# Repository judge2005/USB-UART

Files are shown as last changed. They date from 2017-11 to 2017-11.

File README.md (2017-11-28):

# USB-UART
A USB to serial adapter specifically designed for programming the ESP01. It uses node-mcu style programming, so no fiddling with buttons is necessary - just change the reset method to 'node-mcu'.

It has enough power to run the ESP01 without the need for an additional power source.

It uses the Silicon Labs CP2102N, so it can detect the charge protocol supported by the USB port it is plugged in to. You will have to use the Silicon Labs Express Configurator to set that up.

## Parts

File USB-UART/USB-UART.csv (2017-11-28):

Id | Designator | Package | Quantity | Designation | Supplier and ref
1 | C1,C2 | SparkFun-Capacitors-0603 | 2 | 1uF |  | got
2 | C3 | SparkFun-Capacitors-0603 | 1 | 4.7uF |  | got
3 | C4 | SparkFun-Capacitors-0603 | 1 | 0.1uF |  | got 50v x7r
5 | D1 | D_SOD-323_HandSoldering | 1 | D_Schottky_Small |  | Got
9 | J1 | SparkFun-Connectors-1X06_NO_SILK | 1 | UART |  | Got
10 | J2 | SparkFun-Connectors-1X04_NO_SILK | 1 | Power |  | got
12 | J5 | SparkFun-Connectors-1X03_NO_SILK | 1 | JumperV |  | got
13 | R1 | SparkFun-Resistors-0603 | 1 | 100k |  | got
15 | R3 | SparkFun-Resistors-0603 | 1 | 1K |  | got
16 | R4,R6,R7 | SparkFun-Resistors-0603 | 3 | 470 |  | got
17 | R5,R11 | SparkFun-Resistors-0603 | 2 | 10K |  | got
18 | U1 | nixiemisc-QFN28G_0.5-5X5MM | 1 | CP2102N |  | got
21 | J6 | SparkFun-Connectors-1X03_NO_SILK | 1 | JumperS |  | got
22 | R8,R9 | SparkFun-Resistors-0603 | 2 | 12K |  | got
23 | R10 | SparkFun-Resistors-0603 | 1 | 4.7K |  | got
24 | U4 | nixiemisc-UMT6 | 1 | UMH3NUMT6 |  | got
25 | J4 | SparkFun-Connectors-1X05_NO_SILK | 1 | Charge |  | got
27 | G*** | mermaid_l | 1 | LOGO |  | got
4 | C5 | SparkFun-Capacitors-0603 | 1 | 100pF |  | *
6 | D2 | SparkFun-LED-LED-0603 | 1 | SPND |  | yellow
7 | D3 | SparkFun-LED-LED-0603 | 1 | TX |  | red
8 | D4 | SparkFun-LED-LED-0603 | 1 | RX |  | green
11 | J3 | SparkFun-Connectors-USB-B-MICRO-SMD | 1 | USB_MICRO-B_FEMALE-SMT |  | *
14 | R2 | SparkFun-Resistors-0603 | 1 | 1M |  | *
19 | U2 | nixiemisc-SOT25 | 1 | AP2112 |  | *
20 | U3 | nixiemisc-SOT143 | 1 | ESD |  | got one, maybe get more *
26 | J7 | Socket_Strip_Straight_2x04_Pitch2.54mm | 1 | ESP01

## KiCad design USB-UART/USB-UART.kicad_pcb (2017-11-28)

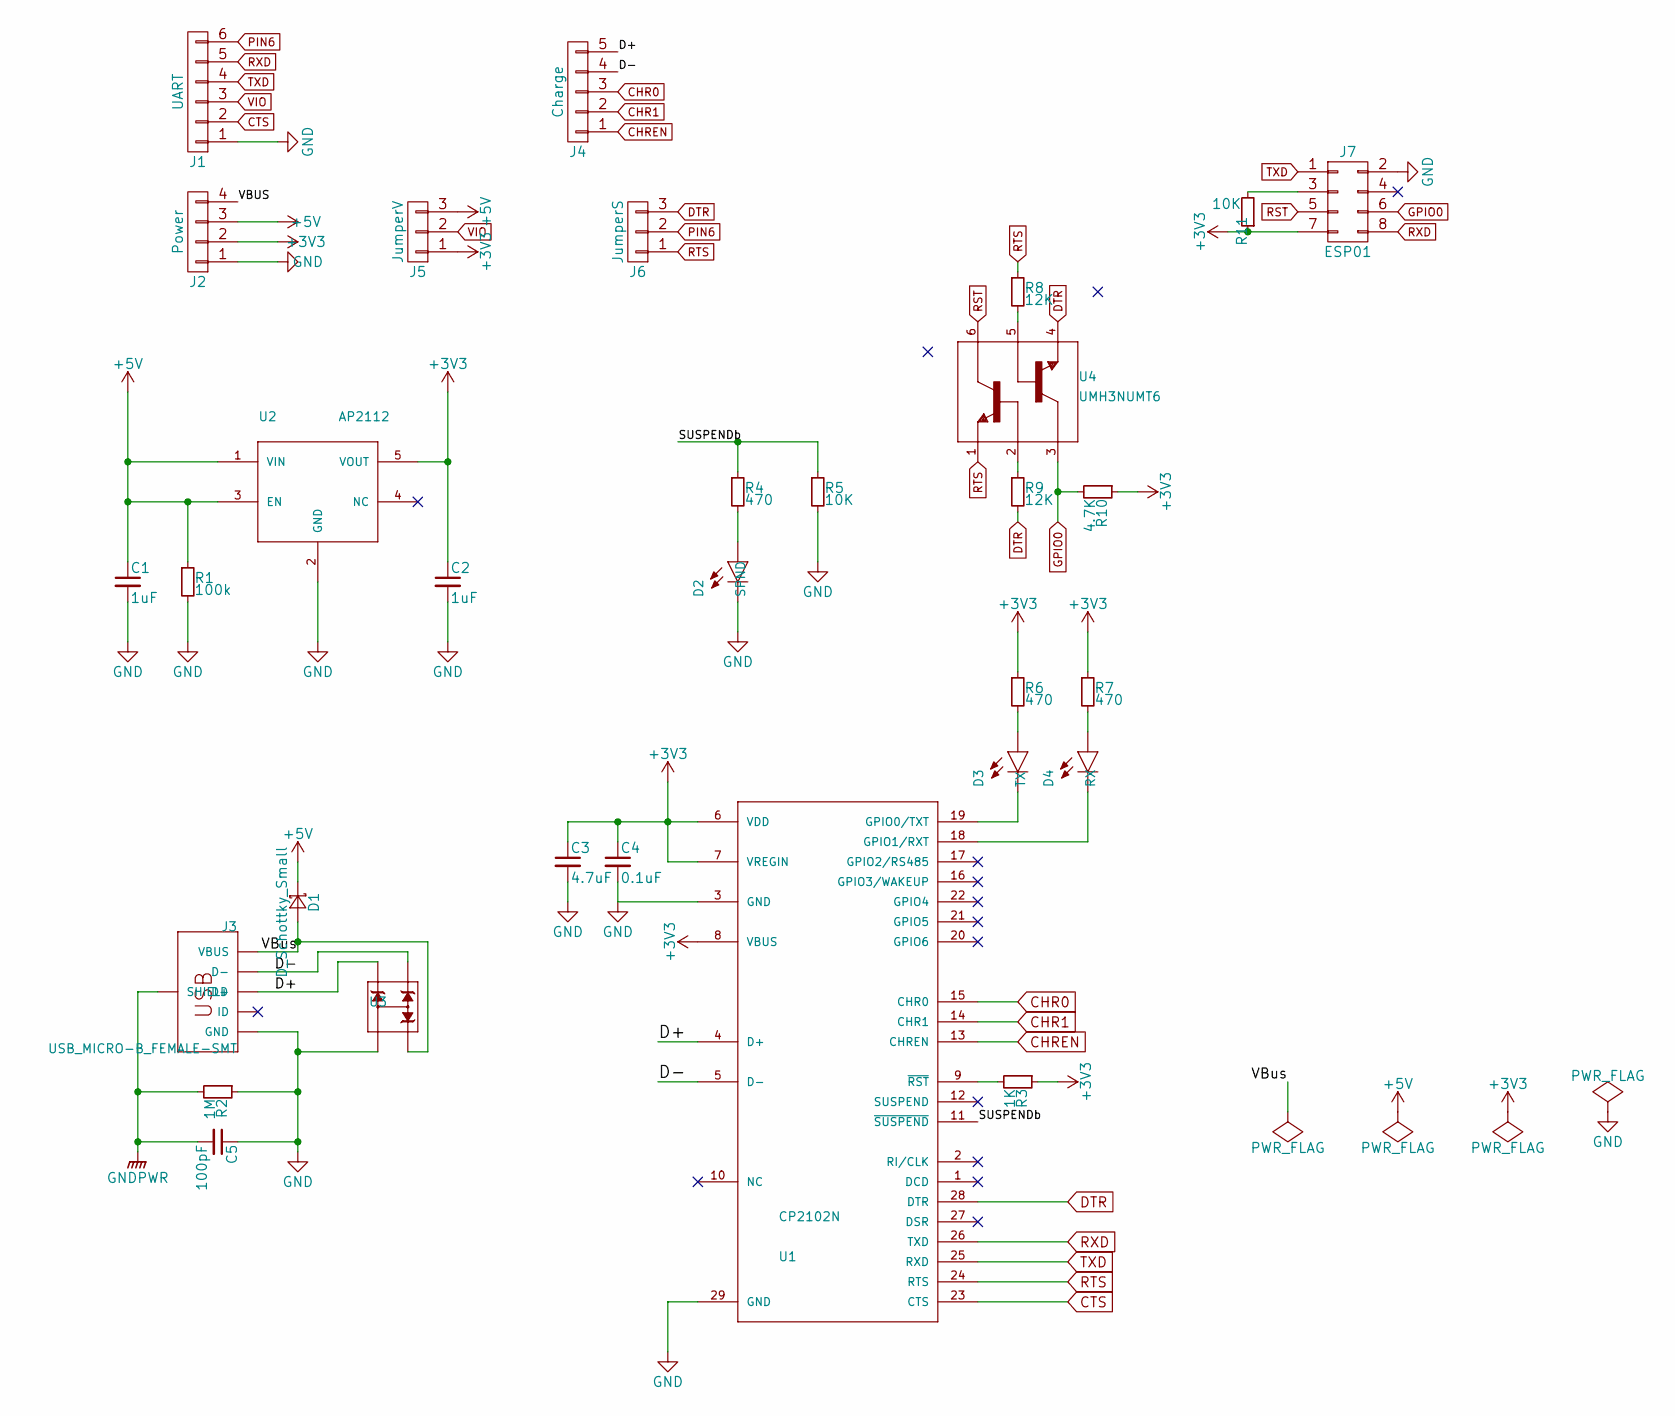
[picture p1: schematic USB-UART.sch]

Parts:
C1, C2: 1uF; SparkFun-Capacitors-0603
C3: 4.7uF; SparkFun-Capacitors-0603
C4: 0.1uF; SparkFun-Capacitors-0603
C5: 100pF; SparkFun-Capacitors-0603; Rating 1KV
D1: D_Schottky_Small; D_SOD-323_HandSoldering
D2: SPND; SparkFun-LED-LED-0603
D3: TX; SparkFun-LED-LED-0603
D4: RX; SparkFun-LED-LED-0603
J1: UART; SparkFun-Connectors-1X06_NO_SILK
J2: Power; SparkFun-Connectors-1X04_NO_SILK
J3: USB_MICRO-B_FEMALE-SMT; SparkFun-Connectors-USB-B-MICRO-SMD
J4: Charge; SparkFun-Connectors-1X05_NO_SILK
J5: JumperV; SparkFun-Connectors-1X03_NO_SILK
J6: JumperS; SparkFun-Connectors-1X03_NO_SILK
J7: ESP01; Socket_Strip_Straight_2x04_Pitch2.54mm
R1: 100k; SparkFun-Resistors-0603
R2: 1M; SparkFun-Resistors-0603
R3: 1K; SparkFun-Resistors-0603
R4, R6, R7: 470; SparkFun-Resistors-0603
R5, R11: 10K; SparkFun-Resistors-0603
R8, R9: 12K; SparkFun-Resistors-0603
R10: 4.7K; SparkFun-Resistors-0603
U1: CP2102N; nixiemisc-QFN28G_0.5-5X5MM
U2: AP2112; nixiemisc-SOT25
U3: ESD; nixiemisc-SOT143
U4: UMH3NUMT6; nixiemisc-UMT6

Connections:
+3V3: C2.1, C3.1, C4.1, J2.2, J5.1, J7.7, R3.1, R6.1, R7.1, R10.1, R11.1, U1.6 (VDD), U1.7 (VREGIN), U1.8 (VBUS), U2.5 (VOUT)
+5V: C1.1, D1.1 (K), J2.3, J5.3, R1.1, U2.1 (VIN), U2.3 (EN)
/D+: J3.D+, J4.5, U1.4 (D+), U3.4
/D-: J3.D-, J4.4, U1.5 (D-), U3.3
/SUSPENDb: R4.1, R5.1, U1.11 (~SUSPEND~)
/VBUS: D1.2 (A), J2.4, J3.VBUS, U3.2
CHR0: J4.3, U1.15 (CHR0)
CHR1: J4.2, U1.14 (CHR1)
CHREN: J4.1, U1.13 (CHREN)
CTS: J1.2, U1.23 (CTS)
DTR: J6.3, R9.2, U1.28 (DTR), U4.4 (E2)
GND: C1.2, C2.2, C3.2, C4.2, C5.1, D2.C, J1.1, J2.1, J3.GND, J7.2, R1.2, R2.1, R5.2, U1.3 (GND), U1.29 (GND), U2.2 (GND), U3.1
GNDPWR: C5.2, J3.SHIE (SHIELD), R2.2
GPIO0: J7.6, R10.2, U4.3 (C2)
unnamed: D2.A, R4.2
unnamed: D3.A, R6.2
unnamed: D3.C, U1.19 (GPIO0/TXT)
unnamed: D4.A, R7.2
unnamed: D4.C, U1.18 (GPIO1/RXT)
unnamed: J7.3, R11.2
unnamed: R3.2, U1.9 (~RST~)
unnamed: R8.2, U4.5 (B2)
unnamed: R9.1, U4.2 (B1)
PIN6: J1.6, J6.2
RST: J7.5, U4.6 (C1)
RTS: J6.1, R8.1, U1.24 (RTS), U4.1 (E1)
RXD: J1.5, J7.8, U1.26 (TXD)
TXD: J1.4, J7.1, U1.25 (RXD)
VIO: J1.3, J5.2

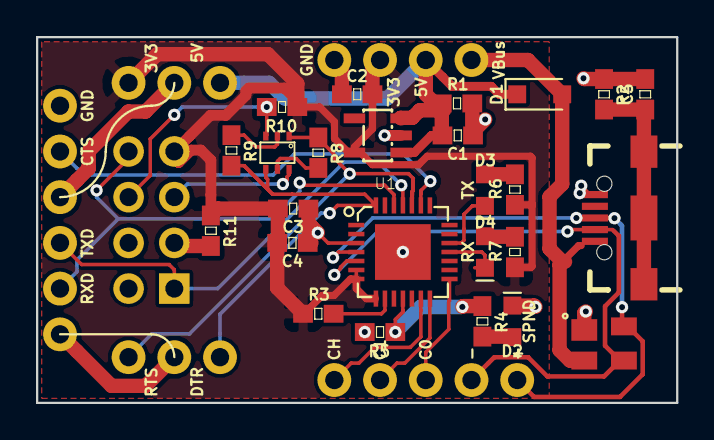
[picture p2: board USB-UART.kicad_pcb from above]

Board: 2 copper layers, 35.6 x 20.3 mm, 31 parts (1 on the bottom side), 29 nets.
